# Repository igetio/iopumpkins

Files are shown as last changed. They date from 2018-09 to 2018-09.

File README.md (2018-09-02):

# IO Pumpkins
* [Pumpkin Control Project Overview](#pumpkin-control-project-overview)
* [Raspberrypi Setup](#raspberrypi-setup)
  + [Installing RabbitMQ and MQTT](#installing-rabbitmq-and-mqtt)
    - [Basic Setup of RabbitMQ](#basic-setup-of-rabbitmq)
    - [Optional - Install RabbitMQ admin site](#optional---install-rabbitmq-admin-site)
  + [Setting up Node site:](#setting-up-node-site)
    - [Basic Setup of Node and sqlite3](#basic-setup-of-node-and-sqlite3)
    - [Running Node as Background Process:](#running-node-as-background-process)
* [Arduino Setup](#arduino-setup)
  + [Basic IDE setup](#basic-ide-setup)

## Pumpkin Control Project Overview
The purpose of this project is to create a raspberry pi controller for a haloween display. It uses node and mqtt running on the rasspberrypi. It uses esp8266 wifi cards to communicate with MQTT and the raspberrypi manages what actions to take for each module and places the messages into MQTT for the modules to process.

There are two parts to this project the rapsberrypi setup and configuration and the arduino module setup 

## Raspberrypi Setup

### Installing RabbitMQ and MQTT
#### Basic Setup of RabbitMQ
1. Install Rabbitmq
    1. Run `sudo apt-get install rabbitmq-server`
2. Install MQTT Plugin
    1. Run `rabbitmq-plugins enable rabbitmq_mqtt`
    2. Run `rabbitmqctl add_user mqtt-test mqtt-test`
    3. Run `rabbitmqctl set_permissions -p / mqtt-test ".*" ".*" ".*"`
    4. Run `rabbitmqctl set_user_tags mqtt-test management`
#### Optional - Install RabbitMQ admin site
1. Run `rabbitmq-plugins enable rabbitmq_management`
2. Create Admin account for login
    1. Run `rabbitmqctl add_user admin admin-password`
    2. Run `rabbitmqctl set_permissions -p / admin ".*" ".*" ".*"`
    3. Run `rabbitmqctl set_user_tags admin administrator`
3. Connect to Console via https://<SERVERNAME>:15672

### Setting up Node site
#### Basic Setup of Node and sqlite3
(The version on my pi is currently v8.x LTS)
1. Install node.js 
    1. Run `curl -sL https://deb.nodesource.com/setup_8.x | sudo -E bash -`
    2. Run `sudo apt install -y nodejs`
2. Install sqlite3
    1. Run `sudo apt-get install sqlite3`
3. Download this repo and extract it
4. Navigate to the nodejs/pumpkin folder and run `npm install`
    1. Optional update dependencies
        1. Run `sudo npm install -g npm-check-updates` 
        2. Run `ncu -u`
        3. Run `npm install`
5. Create the database with `sqlite3 pumpkinpi.db < pumpkinpi.sql`
6. Start the node server `npm start` 
#### Running Node as Background Process
1. Run `sudo npm install -g forever`
2. from the `nodejs/pumpkin` folder run `forever start -w ./bin/www`

## Arduino Setup
### Basic IDE setup

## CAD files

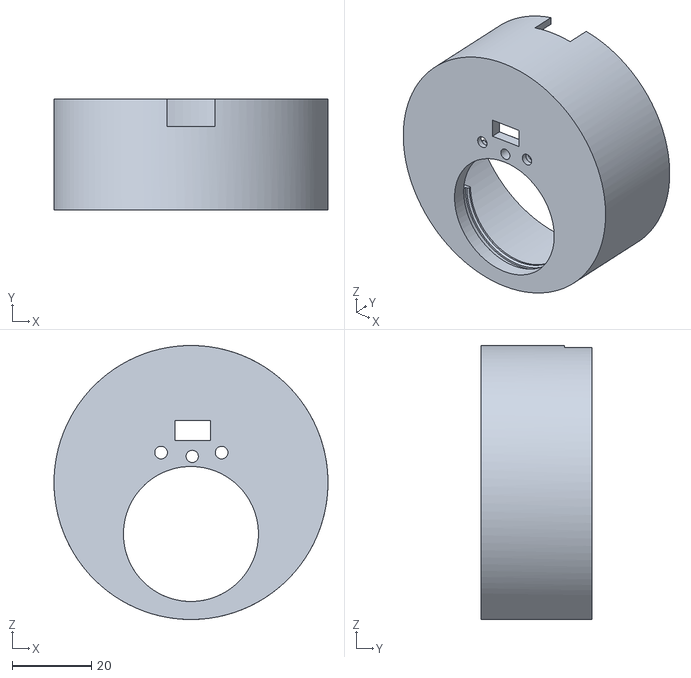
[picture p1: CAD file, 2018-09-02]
3dFiles/prop-body.stl
69.0 x 28.0 x 69.0

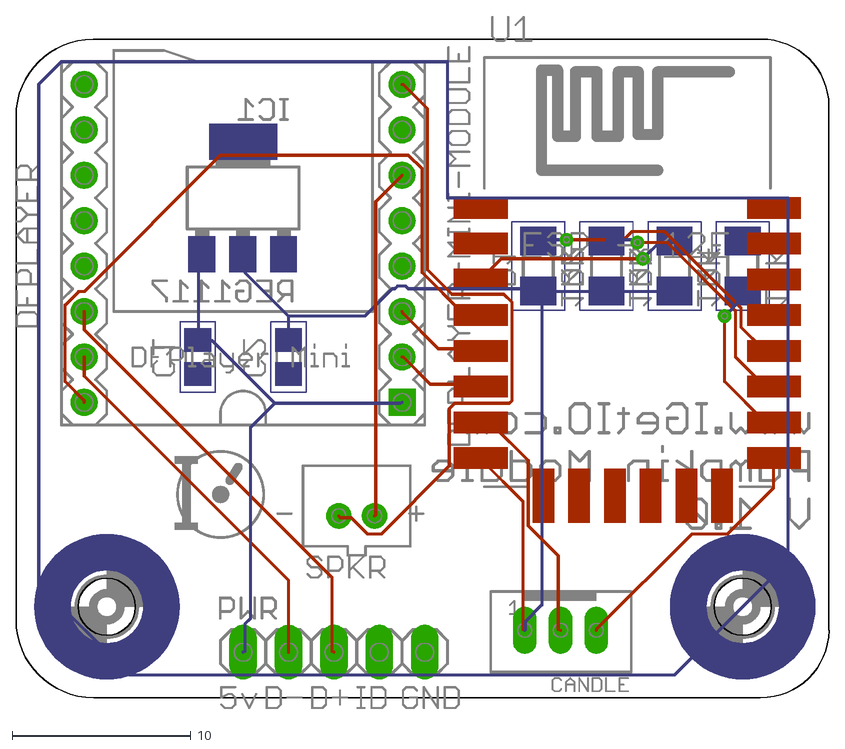
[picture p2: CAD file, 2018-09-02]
schematics/Prop Module.dxf
45.5 x 38.7

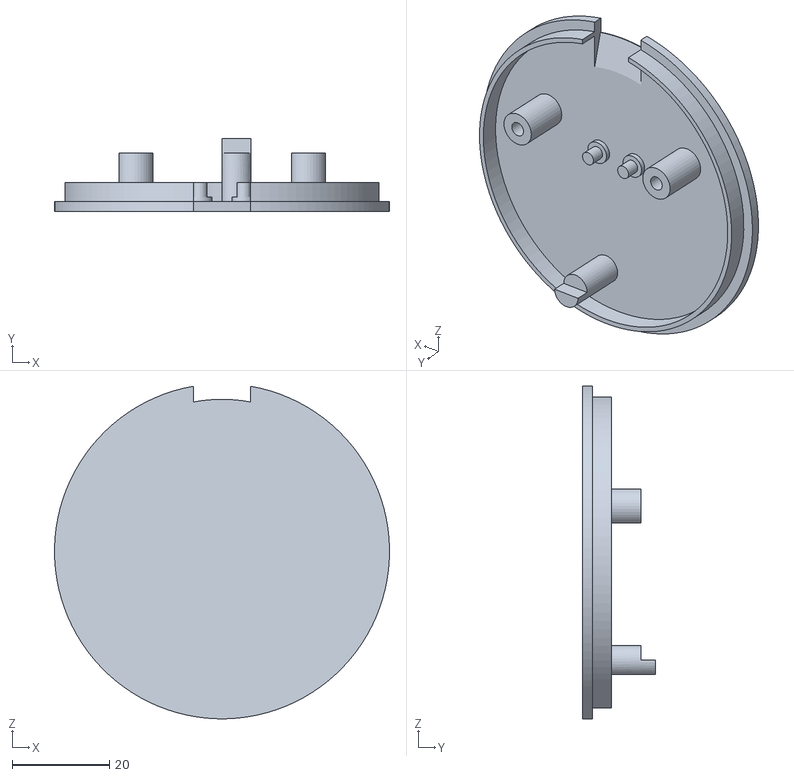
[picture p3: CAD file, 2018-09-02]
3dFiles/prop-base.stl
69.0 x 15.0 x 68.5

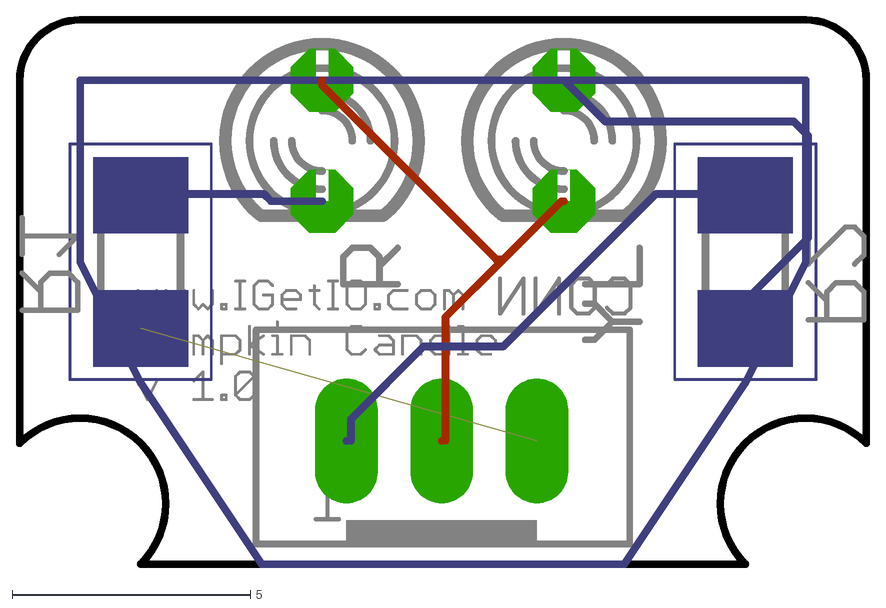
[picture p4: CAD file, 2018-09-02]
schematics/candle.dxf
17.9 x 11.6

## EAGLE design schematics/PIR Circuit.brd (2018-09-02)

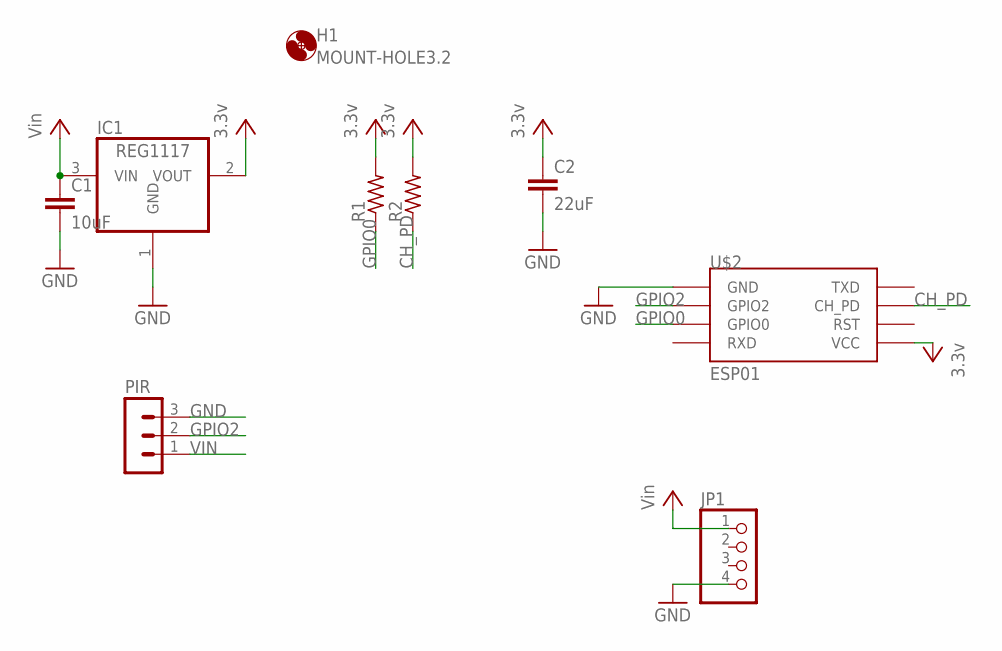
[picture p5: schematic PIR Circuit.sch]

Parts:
C1: 10uF; C0805
C2: 22uF; C0805
H1: MOUNT-HOLE3.2; 3,2
IC1: REG1117; SOT223
JP1: PINHD-1X4/90; 1X04/90
PIR: MA03-1
R1, R2: R-US_M1206; M1206
U$2: ESP01

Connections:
3.3V: C2.1, IC1.2 (VOUT), R1.2, R2.2, U$2.VCC
CH_PD: R2.1, U$2.CH_PD
GND: C1.2, C2.2, IC1.1 (GND), JP1.4, PIR.3, U$2.GND
GPIO0: R1.1, U$2.GPIO0
GPIO2: PIR.2, U$2.GPIO2
VIN: C1.1, IC1.3 (VIN), JP1.1, PIR.1

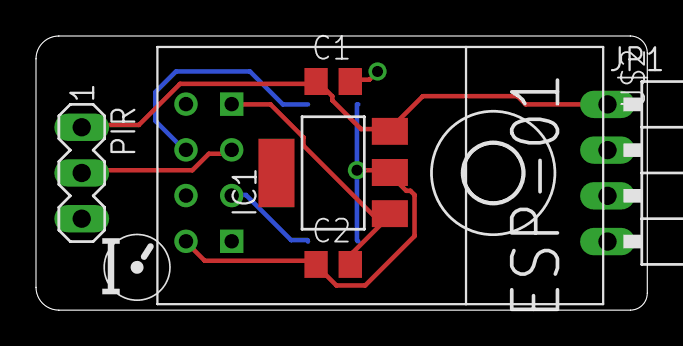
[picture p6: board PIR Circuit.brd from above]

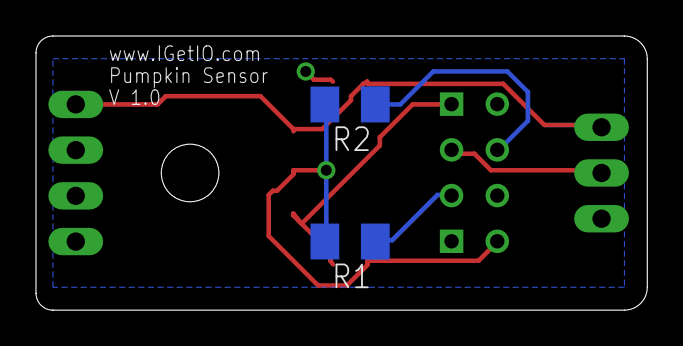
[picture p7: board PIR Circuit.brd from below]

Board: 2 copper layers, 34.0 x 15.2 mm, 10 parts (2 on the bottom side), 6 nets.

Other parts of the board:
U$1: IGETIO-0.25

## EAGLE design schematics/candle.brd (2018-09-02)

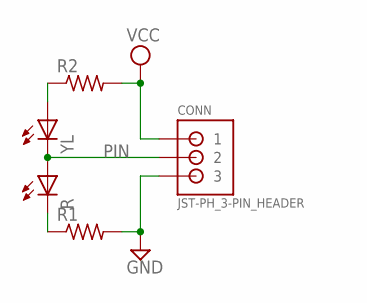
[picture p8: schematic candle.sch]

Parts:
CONN: JST-PH_3-PIN_HEADER; JST_B3B-PH_HEADER
R: LED3MM
R1, R2: R-US_M1206; M1206
YL: LED3MM

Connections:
GND: CONN.P3 (3), R1.2
unnamed: R2.1, YL.A
unnamed: R.K (C), R1.1
PIN: CONN.P2 (2), R.A, YL.K (C)
VCC: CONN.P1 (1), R2.2

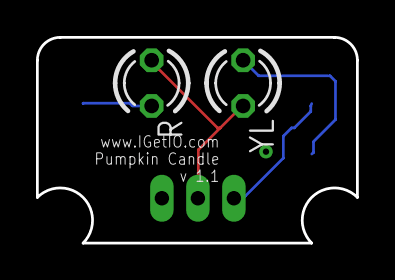
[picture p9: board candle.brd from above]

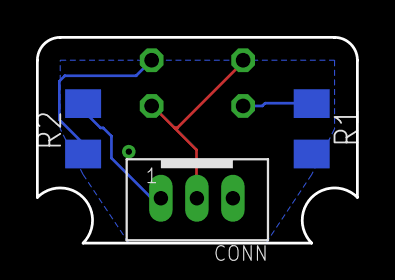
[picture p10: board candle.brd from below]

Board: 2 copper layers, 17.8 x 11.4 mm, 5 parts (3 on the bottom side), 5 nets.

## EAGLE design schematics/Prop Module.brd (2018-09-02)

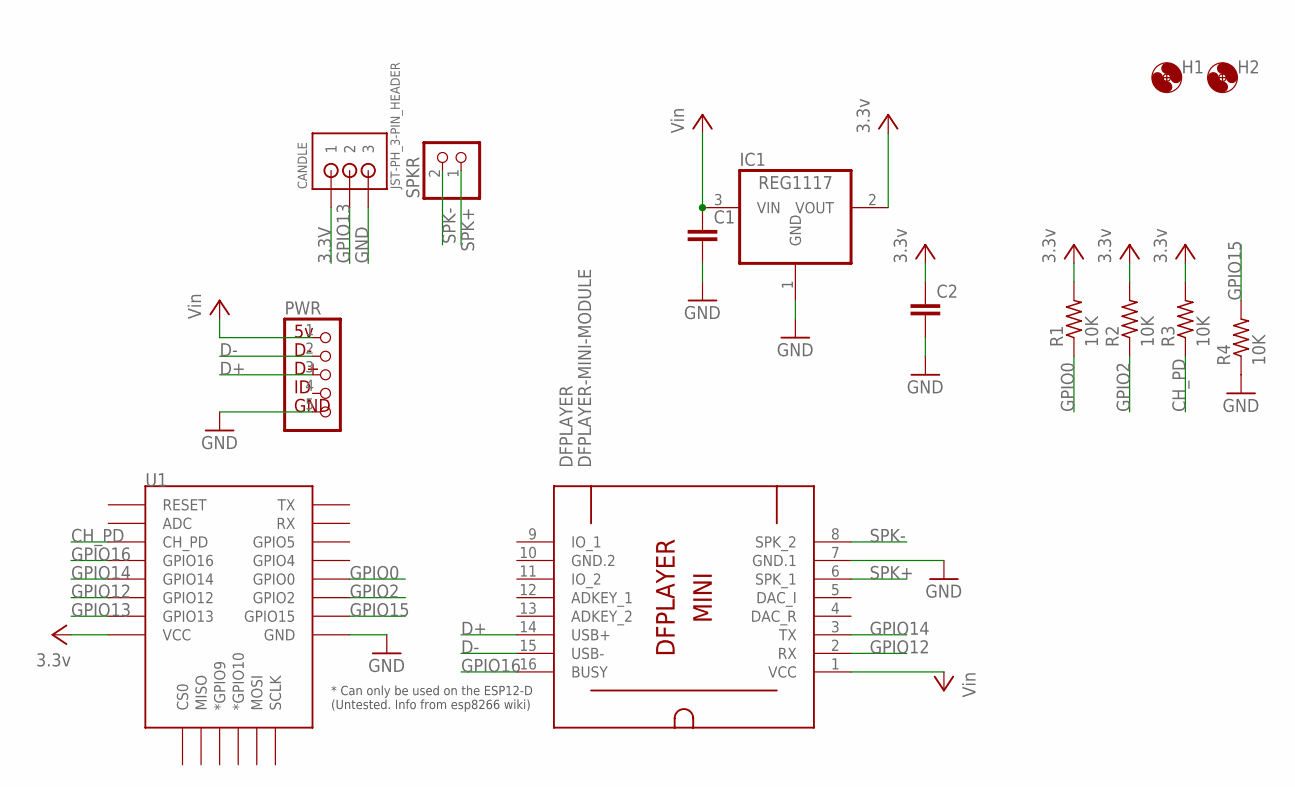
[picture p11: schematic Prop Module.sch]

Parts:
C1, C2: C; C0805
CANDLE: JST-PH_3-PIN_HEADER; JST_B3B-PH_HEADER
DFPLAYER: DFPLAYER-MINI-MODULE
H1, H2: MOUNT-HOLE3.2; 3,2
IC1: REG1117; SOT223
PWR: USB_BRK-1X5; 1X05
R1, R2, R3, R4: 10K; M1206
SPKR: JST_2PIN-THM; JST-PH-2-THM
U1: ESP12ESMD; ESP12E-SMD

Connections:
3.3V: C2.1, CANDLE.P1 (1), IC1.2 (VOUT), R1.2, R2.2, R3.2, U1.VCC
CH_PD: R3.1, U1.CH_PD
D+: DFPLAYER.14 (USB+), PWR.3
D-: DFPLAYER.15 (USB-), PWR.2
GND: C1.2, C2.2, CANDLE.P3 (3), DFPLAYER.7 (GND.1), IC1.1 (GND), PWR.5, R4.1, U1.GND
GND.2: DFPLAYER.10 (GND.2)
GPIO0: R1.1, U1.GPIO0
GPIO2: R2.1, U1.GPIO2
GPIO12: DFPLAYER.2 (RX), U1.GPIO12
GPIO13: CANDLE.P2 (2), U1.GPIO13
GPIO14: DFPLAYER.3 (TX), U1.GPIO14
GPIO15: R4.2, U1.GPIO15
GPIO16: DFPLAYER.16 (BUSY), U1.GPIO16
SPK+: DFPLAYER.6 (SPK_1), SPKR.1 (2)
SPK-: DFPLAYER.8 (SPK_2), SPKR.2 (1)
VIN: C1.1, DFPLAYER.1 (VCC), IC1.3 (VIN), PWR.1

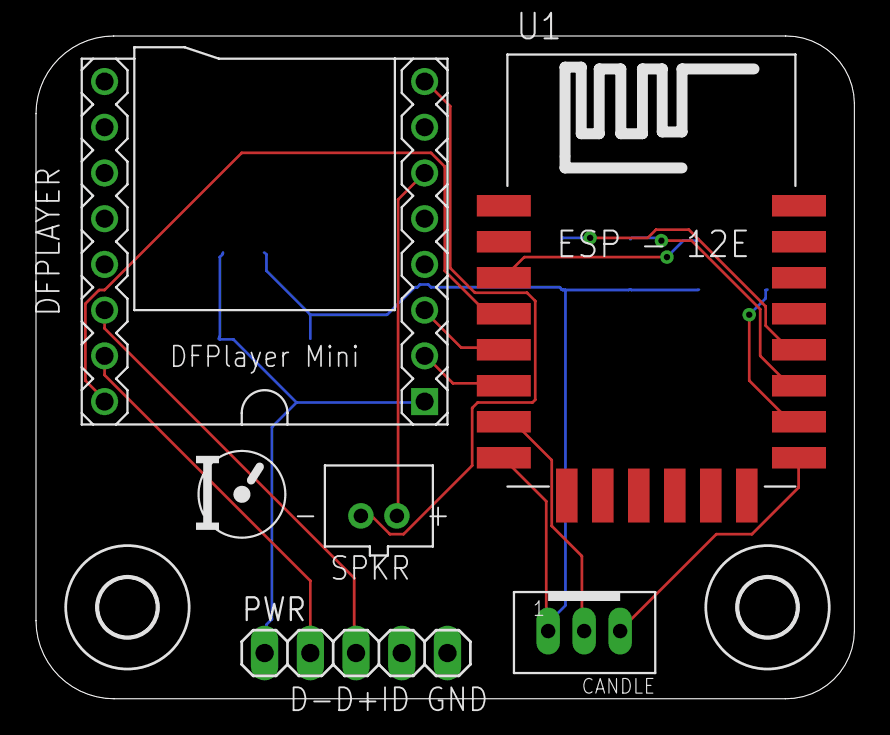
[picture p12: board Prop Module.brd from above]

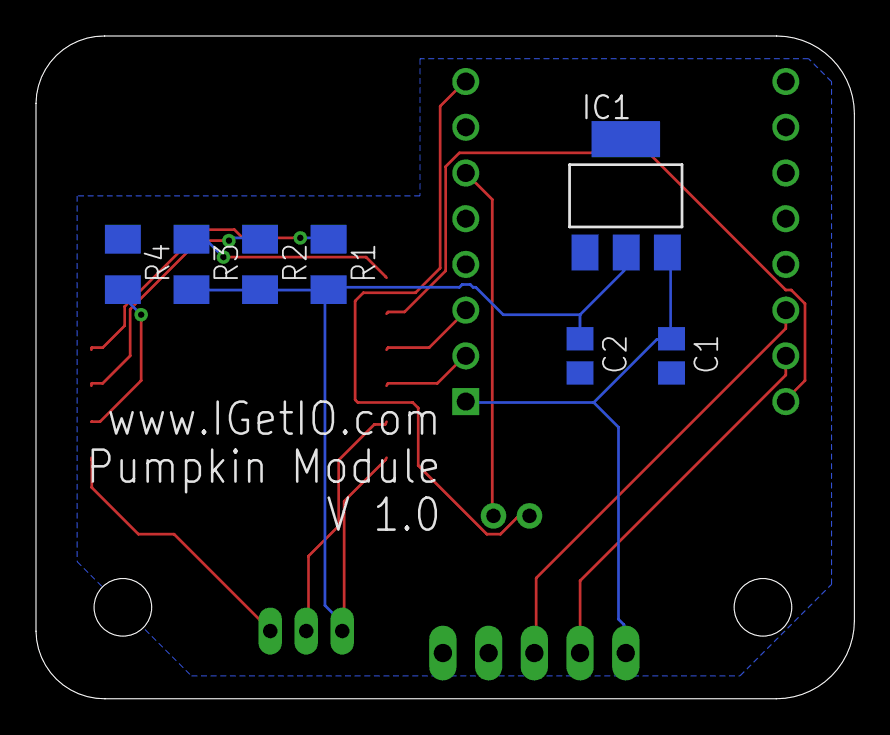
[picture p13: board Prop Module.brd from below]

Board: 2 copper layers, 45.5 x 36.8 mm, 15 parts (7 on the bottom side), 15 nets.

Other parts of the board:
U$1: IGETIO-0.33

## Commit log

2017-09-17 Primary Update
    Adding all files to the project for current setup of scripts
2018-09-02 Updating STLs
    [prop-base.stl, prop-body.stl]
2018-09-02 Adding Schematics
    [PIR Circuit.brd, PIR Circuit.sch, Prop Module.brd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]

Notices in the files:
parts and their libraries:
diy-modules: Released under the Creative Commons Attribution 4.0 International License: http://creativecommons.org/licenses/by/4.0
